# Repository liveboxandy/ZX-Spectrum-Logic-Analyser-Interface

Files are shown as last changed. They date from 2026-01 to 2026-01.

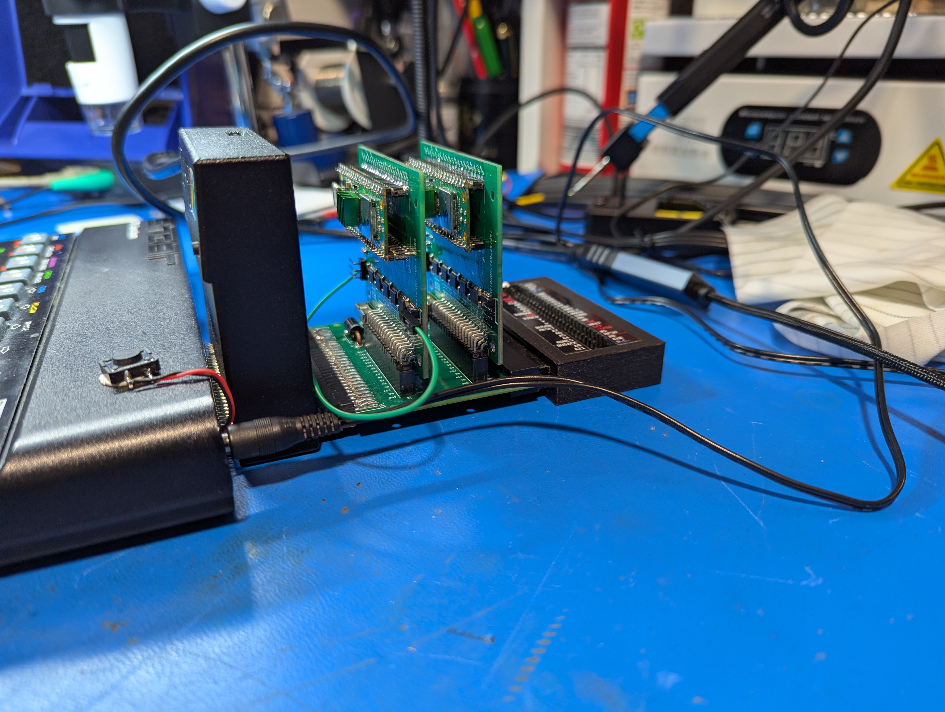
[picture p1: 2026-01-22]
Pictures/ZX Interface V3.2-2.jpg

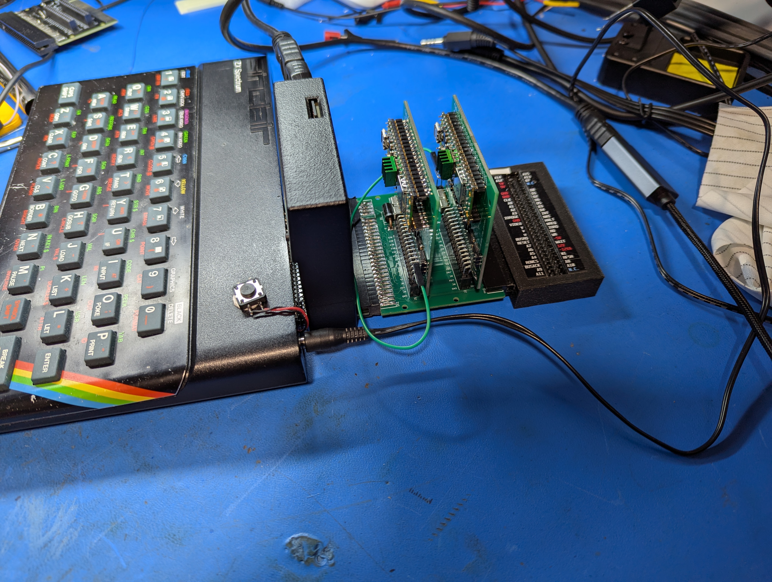
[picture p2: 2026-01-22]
Pictures/ZX Interface V3.2.jpg

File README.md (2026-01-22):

# ZX-Spectrum-Logic-Analyser-Interface
Copied and Modified from an original idea (V3.1) by HappyLittleDiodes(Jim)

Increased space between Logic Analyser Connectors so as to allow for Pico on 10mm headers on Logic Analyser PCB's

PCB size increased to allow for the above

Added 3 pin header to allow for manual connection to the unused channels (6,7 and 26)

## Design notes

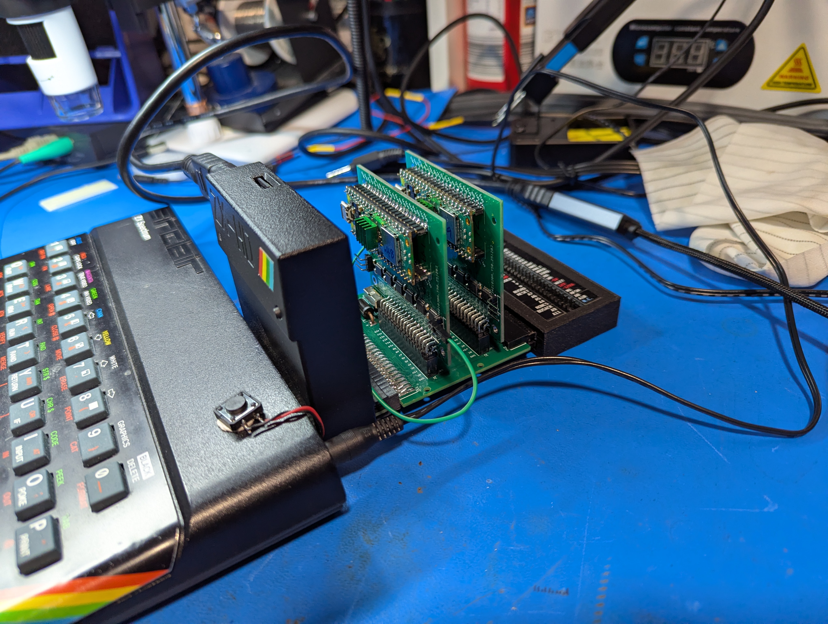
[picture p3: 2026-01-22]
Pictures/ZX Interface V3.2-1.jpg

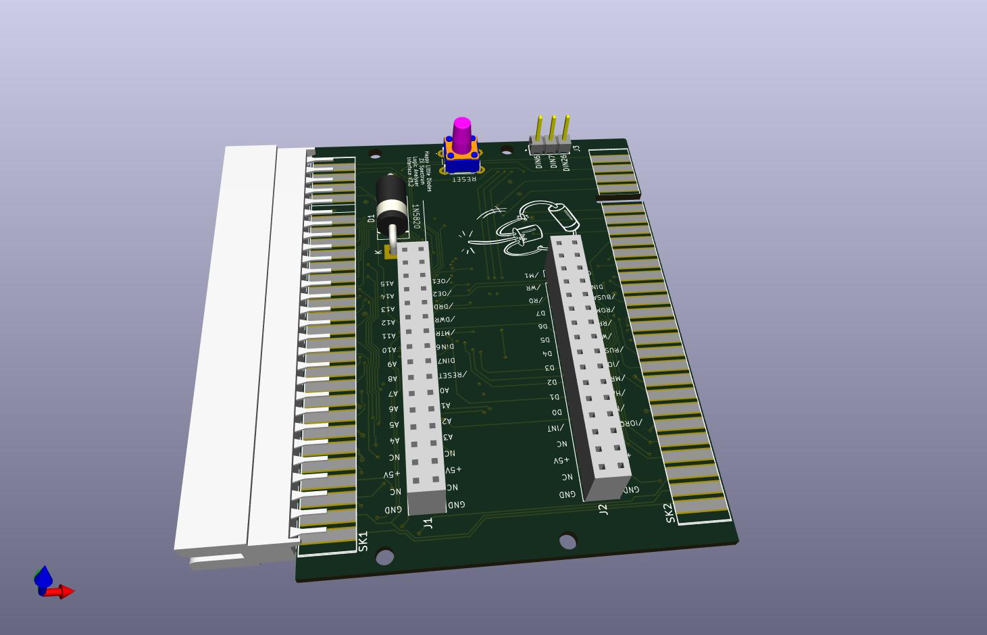
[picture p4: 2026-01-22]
ZX Interface.jpg

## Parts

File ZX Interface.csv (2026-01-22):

Source: | E:\Kicad\ZX Interface 3.2\ZX Interface.kicad_sch
Date: | 2025-12-03T10:05:21+0000
Tool: | Eeschema 9.0.5
Generator: | C:\Program Files\KiCad\7.0\bin\scripting\plugins/bom_csv_grouped_by_value_with_fp.py
Component Count: | 7
Ref | Qnty | Value | Cmp name | Footprint | Description | Vendor | DNP
D1 | 1 | 1N5820 | 1N5820 | Diode_THT:D_DO-201AD_P15.24mm_Horizontal | 20V 3A Schottky Barrier Rectifier Diode, DO-201AD
J1, J2 | 2 | SSQ-116-XX-X-D | SSQ-116-XX-X-D | Mods:SAMTEC_SSQ-116-XX-X-D
J3 | 1 | Conn_01x03 | TSW-103-07-G-S | Mods:SAMTEC_TSW-103-07-G-S
S1 | 1 | SKHHANA010 | SKHHANA010 | Mods:SKHHANA010 | Tact switch,PCB,SPST,black,0.98N o/force Black Stem Tactile Switch, SPST-NO 50 mA 9.5mm
SK1, SK2 | 2 | ZX Spectrum | expansion_port_2 | Mods:ZX_Spectrum_BUS_Edge_Connector Horizontal

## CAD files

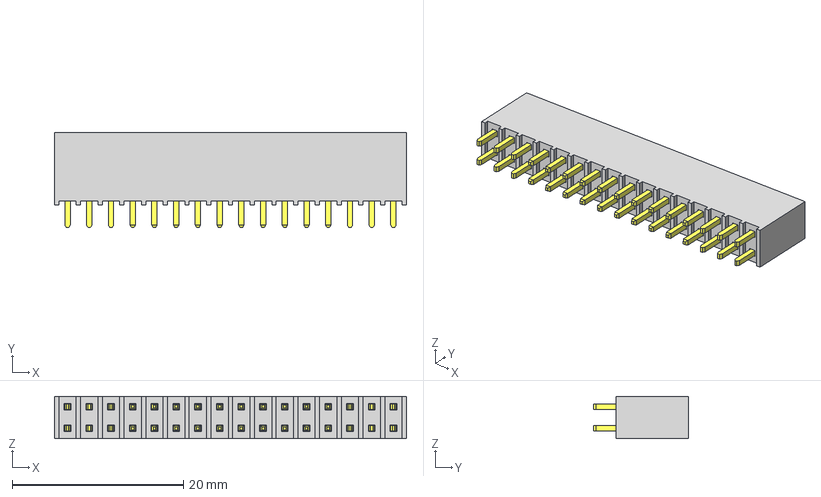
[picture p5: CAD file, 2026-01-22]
Mods/SSQ-116-01-S-D.stp
41.1 x 11.2 x 4.95 mm
T1SSQ-116-01-S-D
P2SSQ-116-01-S-D

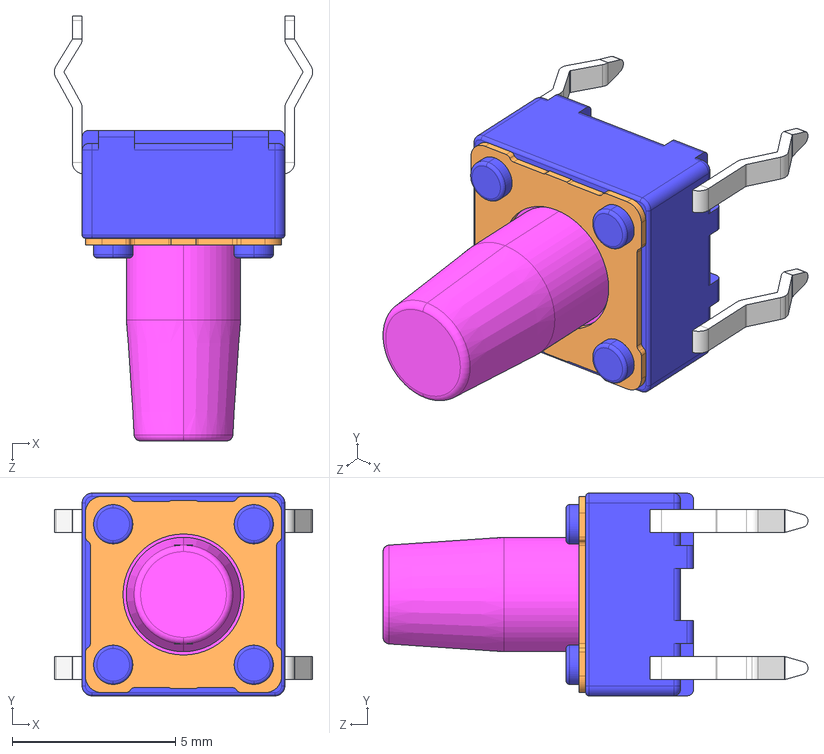
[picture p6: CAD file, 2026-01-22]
Mods/SKHHAN.STEP
7.90 x 6.20 x 13.0 mm

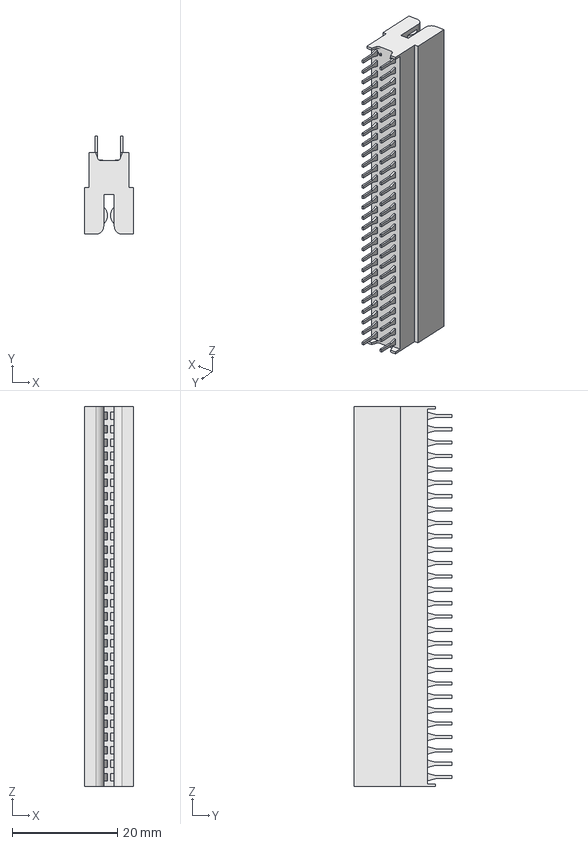
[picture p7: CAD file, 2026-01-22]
Mods/ZX_Spectrum_BUS_Edge_Connector Horizontal.stp
9.35 x 18.7 x 72.1 mm

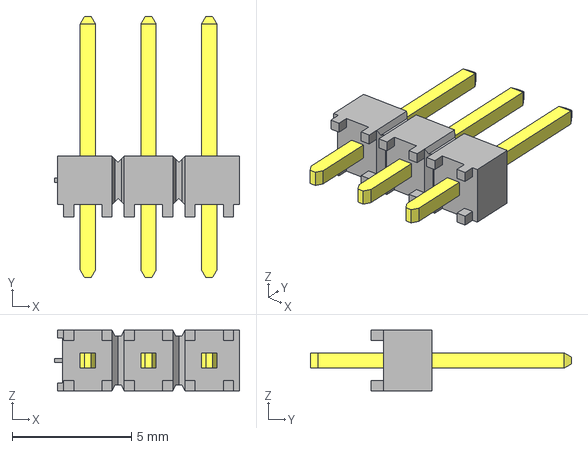
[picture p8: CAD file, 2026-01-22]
Mods/TSW-103-07-G-S.stp
7.75 x 10.9 x 2.54 mm
TSW-103-07-G-S_body
T-1S6-07-TSW-1-07-3-S

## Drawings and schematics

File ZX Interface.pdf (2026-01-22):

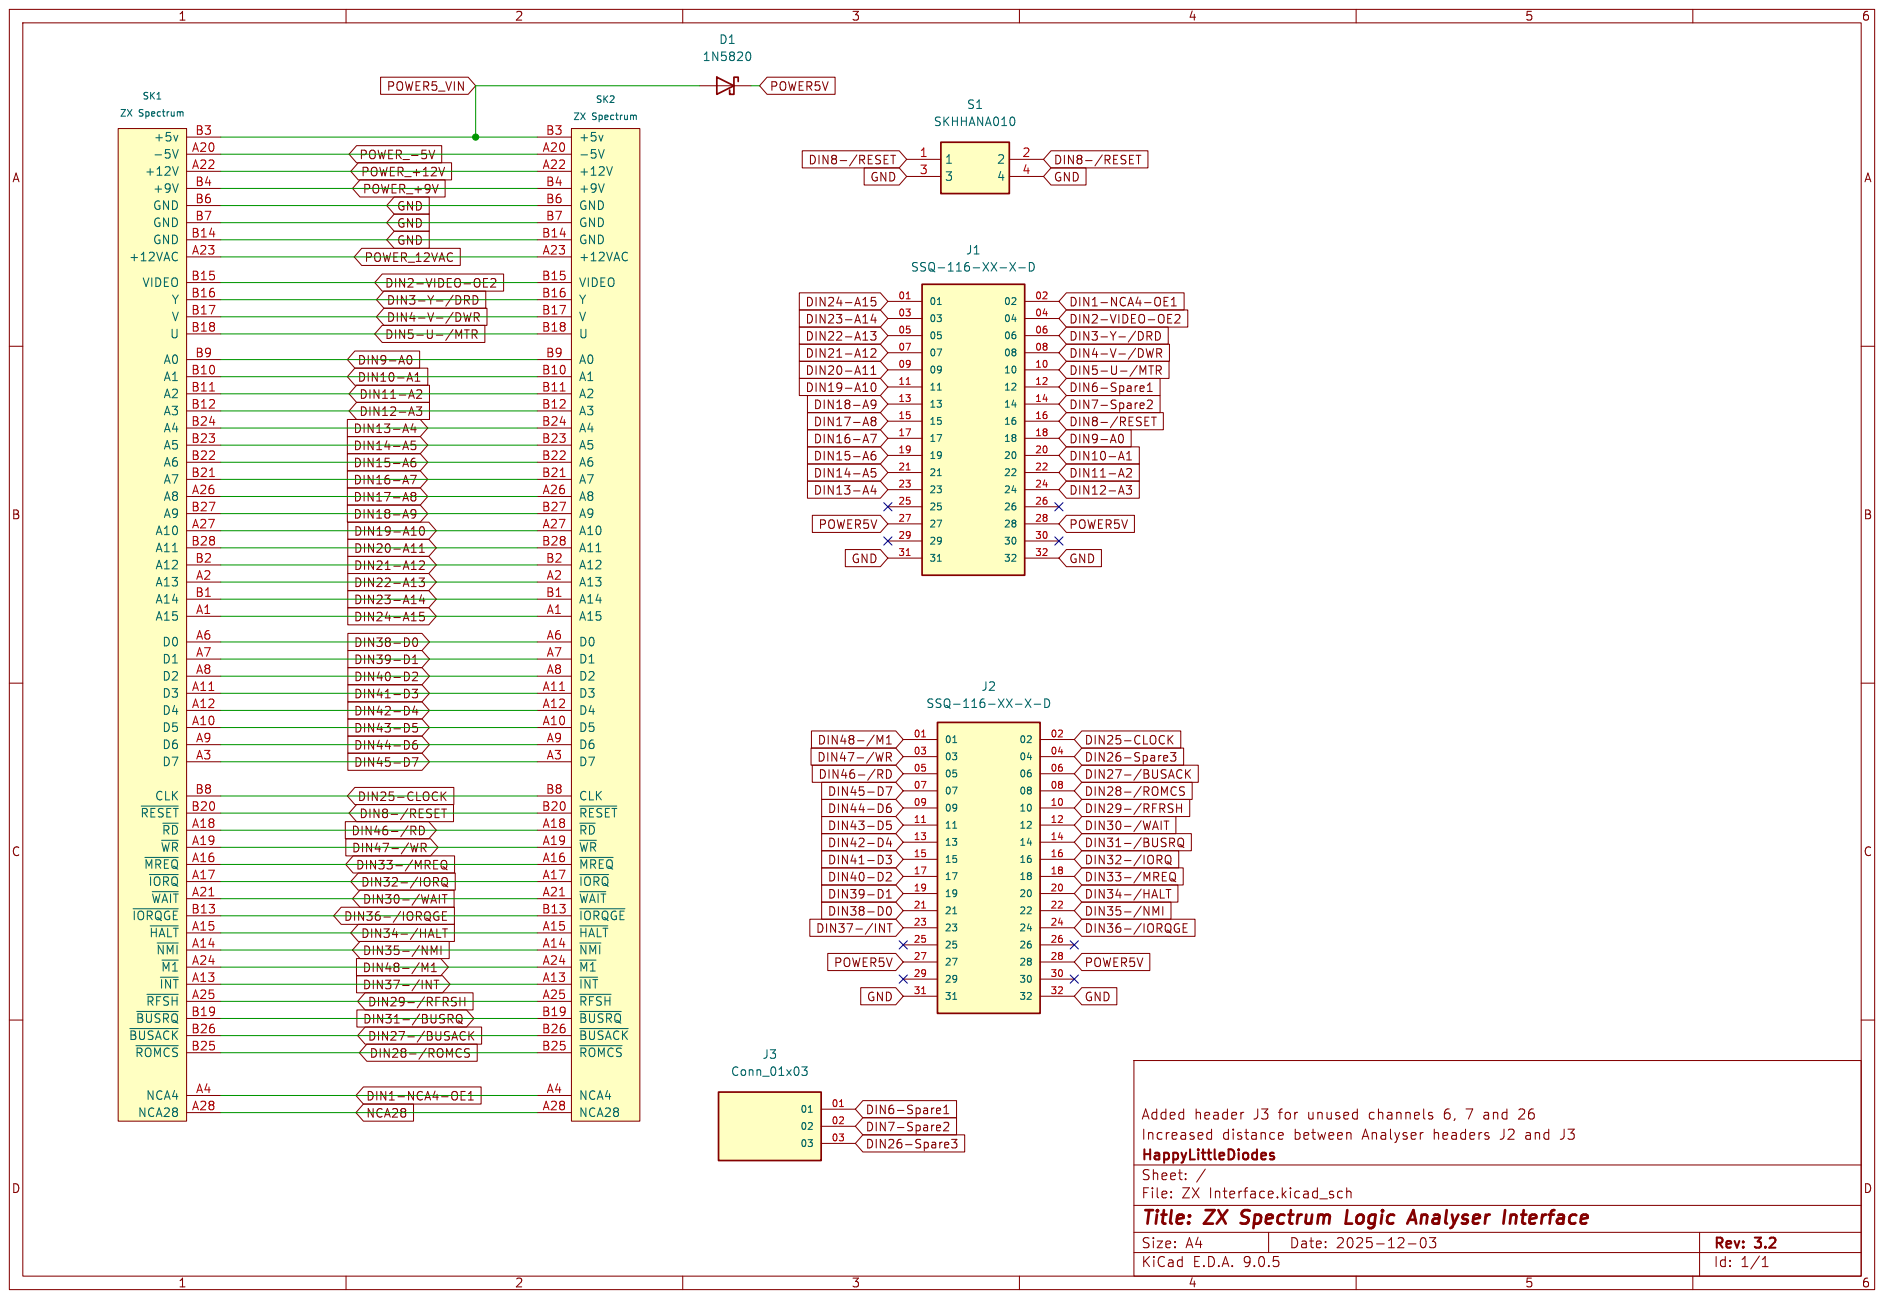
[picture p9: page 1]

DIN36-/IORQGE DIN35-/NMI DIN34-/HALT DIN36-/IORQGE DIN37-/INT DIN48-/M1 DIN44-D6 DIN8-/RESET DIN45-D7 DIN30-/WAIT DIN25-CLOCK DIN46-/RD

Id: 1/1 Title: ZX Spectrum Logic Analyser Interface

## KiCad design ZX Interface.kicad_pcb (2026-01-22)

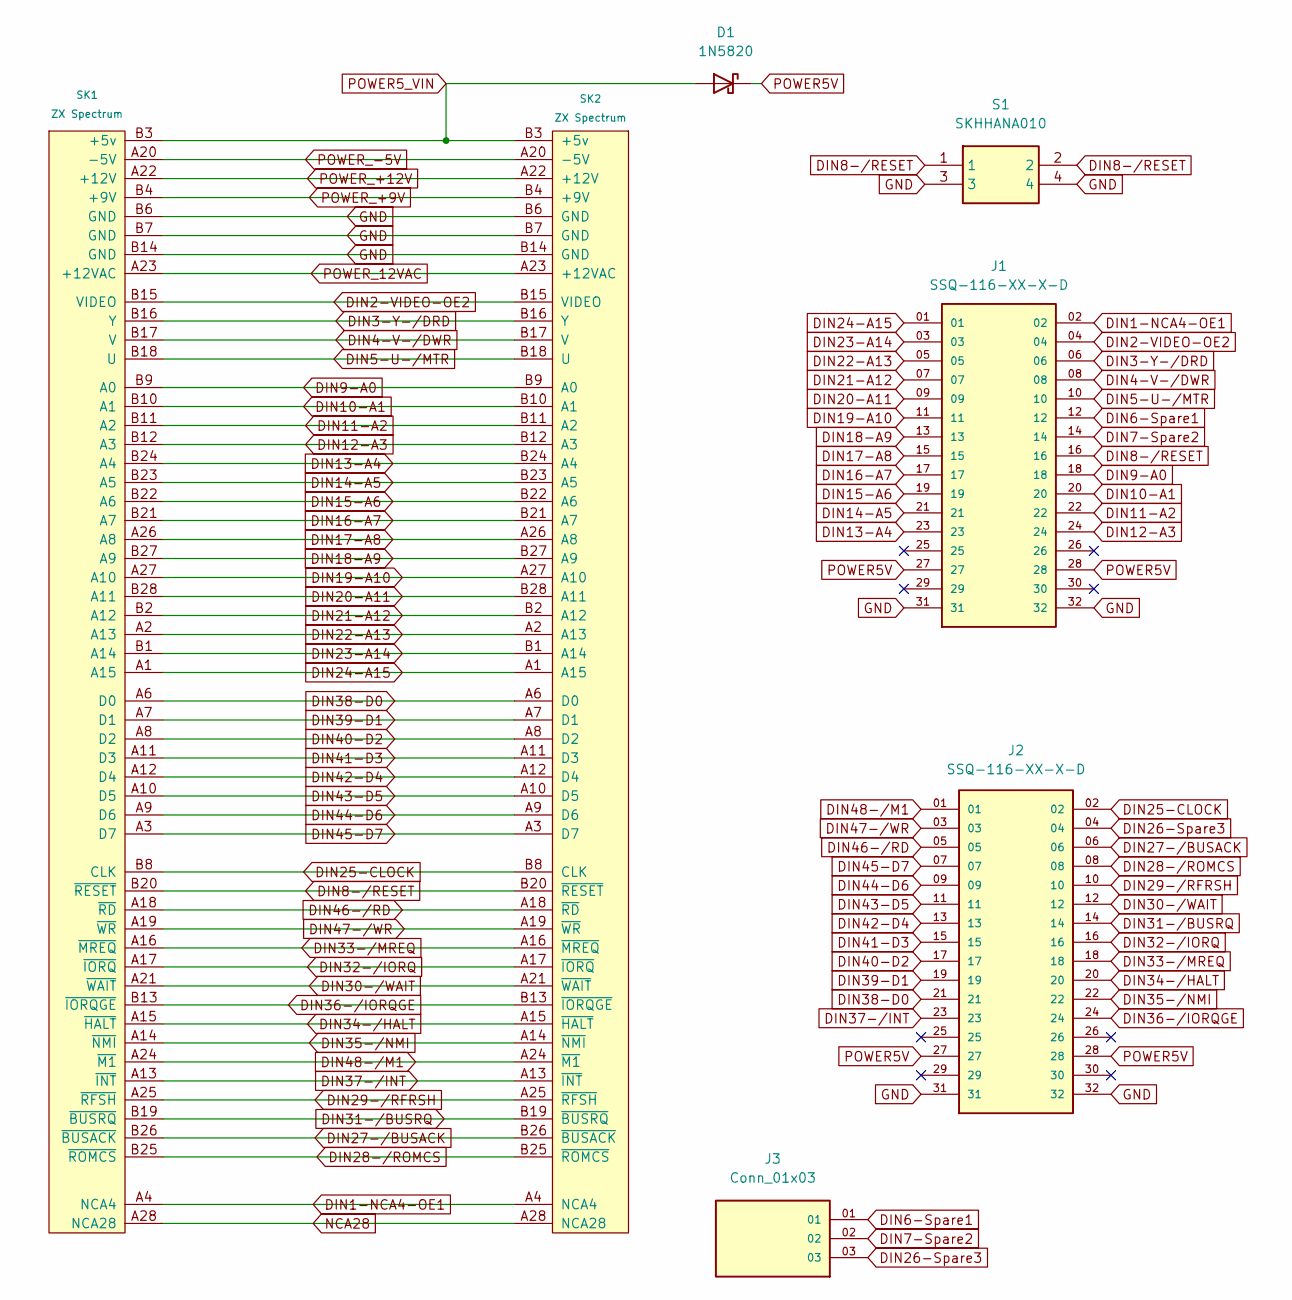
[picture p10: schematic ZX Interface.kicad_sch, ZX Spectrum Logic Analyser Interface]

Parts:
D1: 1N5820; D_DO-201AD_P15.24mm_Horizontal
J1, J2: SSQ-116-XX-X-D; SAMTEC_SSQ-116-XX-X-D; PARTREV A
J3: Conn_01x03; SAMTEC_TSW-103-07-G-S; PARTREV R
S1: SKHHANA010; Mouser Part Number 688-SKHHAN
SK1, SK2: ZX Spectrum; ZX_Spectrum_BUS_Edge_Connector Horizontal

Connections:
DIN1-NCA4-OE1: J1.02, SK1.A4 (NCA4), SK2.A4 (NCA4)
DIN2-VIDEO-OE2: J1.04, SK1.B15 (VIDEO), SK2.B15 (VIDEO)
DIN3-Y-/DRD: J1.06, SK1.B16 (Y), SK2.B16 (Y)
DIN4-V-/DWR: J1.08, SK1.B17 (V), SK2.B17 (V)
DIN5-U-/MTR: J1.10, SK1.B18 (U), SK2.B18 (U)
DIN6-Spare1: J1.12, J3.01
DIN7-Spare2: J1.14, J3.02
DIN8-/RESET: J1.16, S1.1, S1.2, SK1.B20 (~RESET), SK2.B20 (~RESET)
DIN9-A0: J1.18, SK1.B9 (A0), SK2.B9 (A0)
DIN10-A1: J1.20, SK1.B10 (A1), SK2.B10 (A1)
DIN11-A2: J1.22, SK1.B11 (A2), SK2.B11 (A2)
DIN12-A3: J1.24, SK1.B12 (A3), SK2.B12 (A3)
DIN13-A4: J1.23, SK1.B24 (A4), SK2.B24 (A4)
DIN14-A5: J1.21, SK1.B23 (A5), SK2.B23 (A5)
DIN15-A6: J1.19, SK1.B22 (A6), SK2.B22 (A6)
DIN16-A7: J1.17, SK1.B21 (A7), SK2.B21 (A7)
DIN17-A8: J1.15, SK1.A26 (A8), SK2.A26 (A8)
DIN18-A9: J1.13, SK1.B27 (A9), SK2.B27 (A9)
DIN19-A10: J1.11, SK1.A27 (A10), SK2.A27 (A10)
DIN20-A11: J1.09, SK1.B28 (A11), SK2.B28 (A11)
DIN21-A12: J1.07, SK1.B2 (A12), SK2.B2 (A12)
DIN22-A13: J1.05, SK1.A2 (A13), SK2.A2 (A13)
DIN23-A14: J1.03, SK1.B1 (A14), SK2.B1 (A14)
DIN24-A15: J1.01, SK1.A1 (A15), SK2.A1 (A15)
DIN25-CLOCK: J2.02, SK1.B8 (CLK), SK2.B8 (CLK)
DIN26-Spare3: J2.04, J3.03
DIN27-/BUSACK: J2.06, SK1.B26 (~BUSACK), SK2.B26 (~BUSACK)
DIN28-/ROMCS: J2.08, SK1.B25 (~ROMCS), SK2.B25 (~ROMCS)
DIN29-/RFRSH: J2.10, SK1.A25 (~RFSH), SK2.A25 (~RFSH)
DIN30-/WAIT: J2.12, SK1.A21 (~WAIT), SK2.A21 (~WAIT)
DIN31-/BUSRQ: J2.14, SK1.B19 (~BUSRQ), SK2.B19 (~BUSRQ)
DIN32-/IORQ: J2.16, SK1.A17 (~IORQ), SK2.A17 (~IORQ)
DIN33-/MREQ: J2.18, SK1.A16 (~MREQ), SK2.A16 (~MREQ)
DIN34-/HALT: J2.20, SK1.A15 (~HALT), SK2.A15 (~HALT)
DIN35-/NMI: J2.22, SK1.A14 (~NMI), SK2.A14 (~NMI)
DIN36-/IORQGE: J2.24, SK1.B13 (~IORQGE), SK2.B13 (~IORQGE)
DIN37-/INT: J2.23, SK1.A13 (~INT), SK2.A13 (~INT)
DIN38-D0: J2.21, SK1.A6 (D0), SK2.A6 (D0)
DIN39-D1: J2.19, SK1.A7 (D1), SK2.A7 (D1)
DIN40-D2: J2.17, SK1.A8 (D2), SK2.A8 (D2)
DIN41-D3: J2.15, SK1.A11 (D3), SK2.A11 (D3)
DIN42-D4: J2.13, SK1.A12 (D4), SK2.A12 (D4)
DIN43-D5: J2.11, SK1.A10 (D5), SK2.A10 (D5)
DIN44-D6: J2.09, SK1.A9 (D6), SK2.A9 (D6)
DIN45-D7: J2.07, SK1.A3 (D7), SK2.A3 (D7)
DIN46-/RD: J2.05, SK1.A18 (~RD), SK2.A18 (~RD)
DIN47-/WR: J2.03, SK1.A19 (~WR), SK2.A19 (~WR)
DIN48-/M1: J2.01, SK1.A24 (~M1), SK2.A24 (~M1)
GND: J1.31, J1.32, J2.31, J2.32, S1.3, S1.4, SK1.B6 (GND), SK1.B7 (GND), SK1.B14 (GND), SK2.B6 (GND), SK2.B7 (GND), SK2.B14 (GND)
NCA28: SK1.A28 (NCA28), SK2.A28 (NCA28)
POWER5V: D1.1 (K), J1.27, J1.28, J2.27, J2.28
POWER5_VIN: D1.2 (A), SK1.B3 (+5v), SK2.B3 (+5v)
POWER_12VAC: SK1.A23 (+12VAC), SK2.A23 (+12VAC)
POWER_+9V: SK1.B4 (+9V), SK2.B4 (+9V)
POWER_+12V: SK1.A22 (+12V), SK2.A22 (+12V)
POWER_-5V: SK1.A20 (-5V), SK2.A20 (-5V)

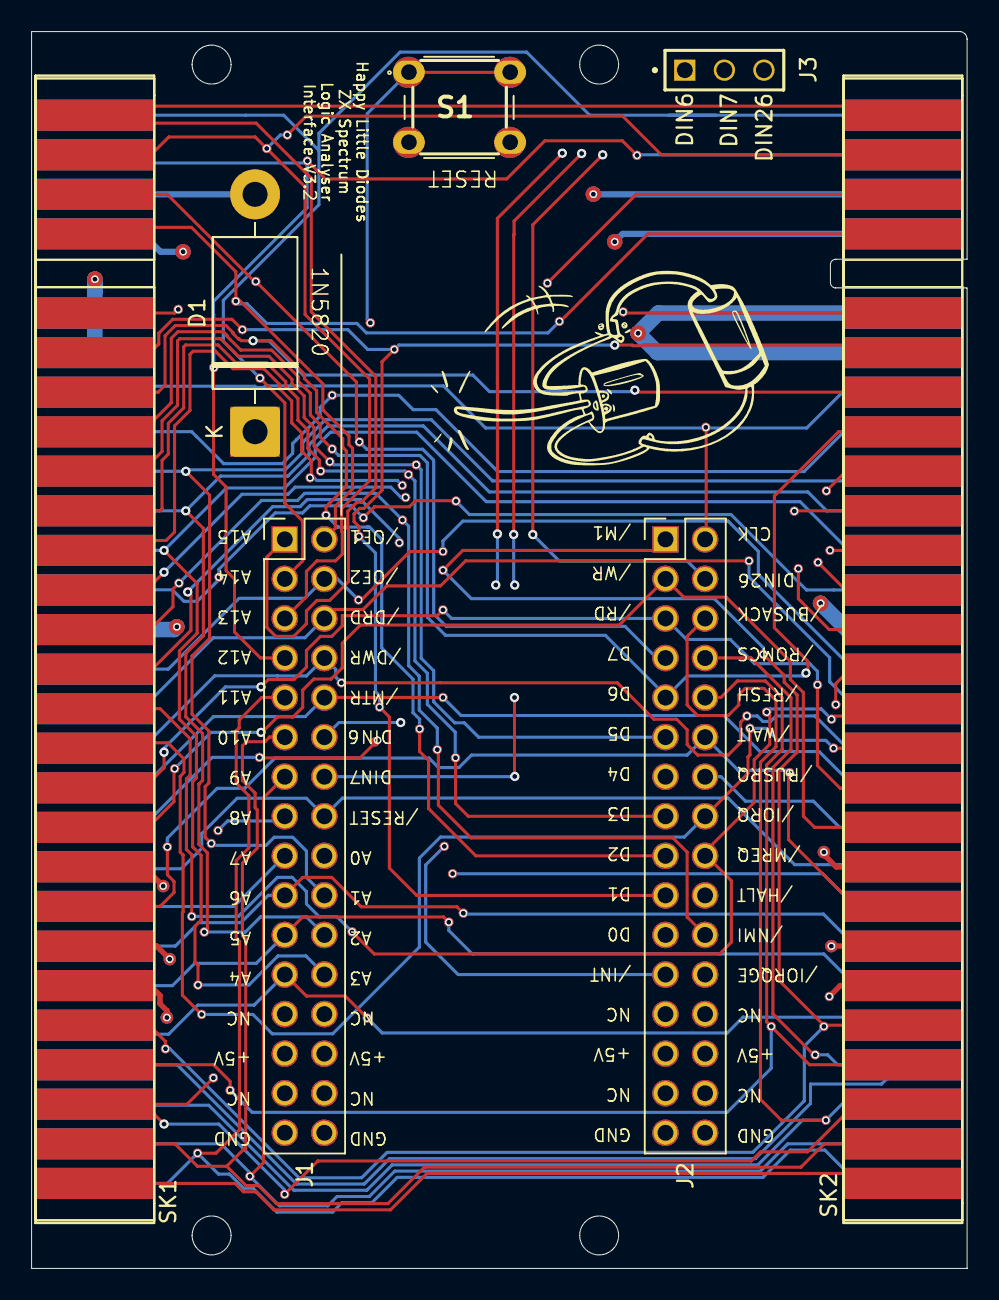
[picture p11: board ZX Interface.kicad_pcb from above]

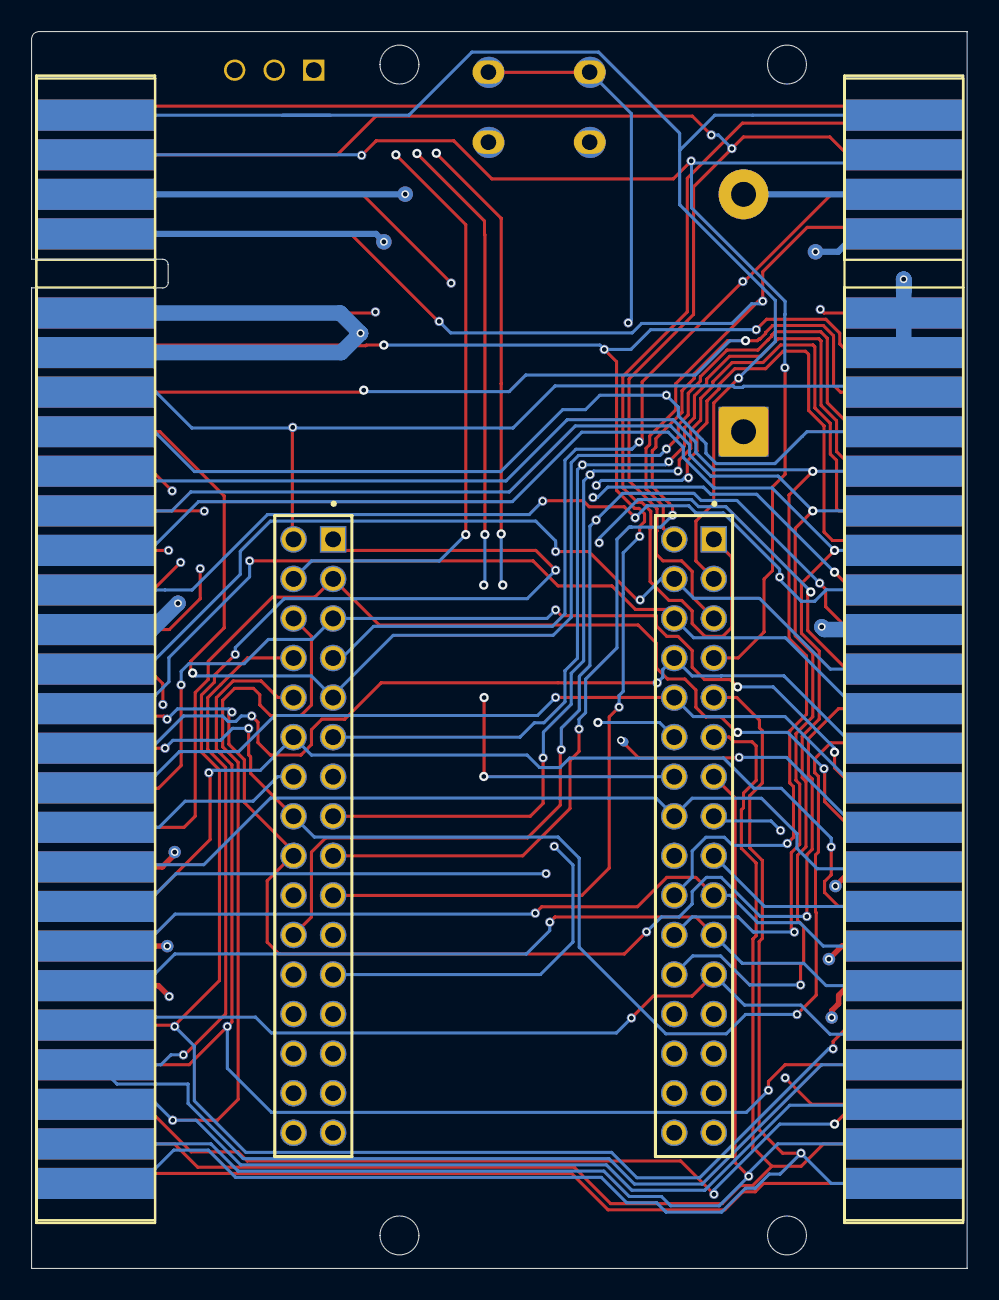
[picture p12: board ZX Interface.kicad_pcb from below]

Board: 4 copper layers, 60.1 x 79.4 mm, 7 parts (2 on the bottom side), 56 nets.

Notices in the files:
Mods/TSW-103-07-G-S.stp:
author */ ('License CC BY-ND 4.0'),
